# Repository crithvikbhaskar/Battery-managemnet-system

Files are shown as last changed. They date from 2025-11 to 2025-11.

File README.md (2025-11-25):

# 🔋 4-Cell Battery Management System (BMS)

This repository features a complete, production-grade **4-Cell Battery Management System (BMS)** design utilizing the **Texas Instruments BQ76920** Analog Front End (AFE) and an **STM32** microcontroller. It is designed to safely monitor, balance, and protect 4-series (4S) Lithium-Ion or Lithium Iron Phosphate (LiFePO4) battery packs.

---

## 📸 Project Visuals & Simulation

### 1. 3D Board Layout & CAD Model
The hardware layout is optimized for low-noise kelvin current sensing and thermal dissipation. It includes input RC filter stages for each cell, back-to-back low-side N-channel protection MOSFETs, and I2C pull-ups.

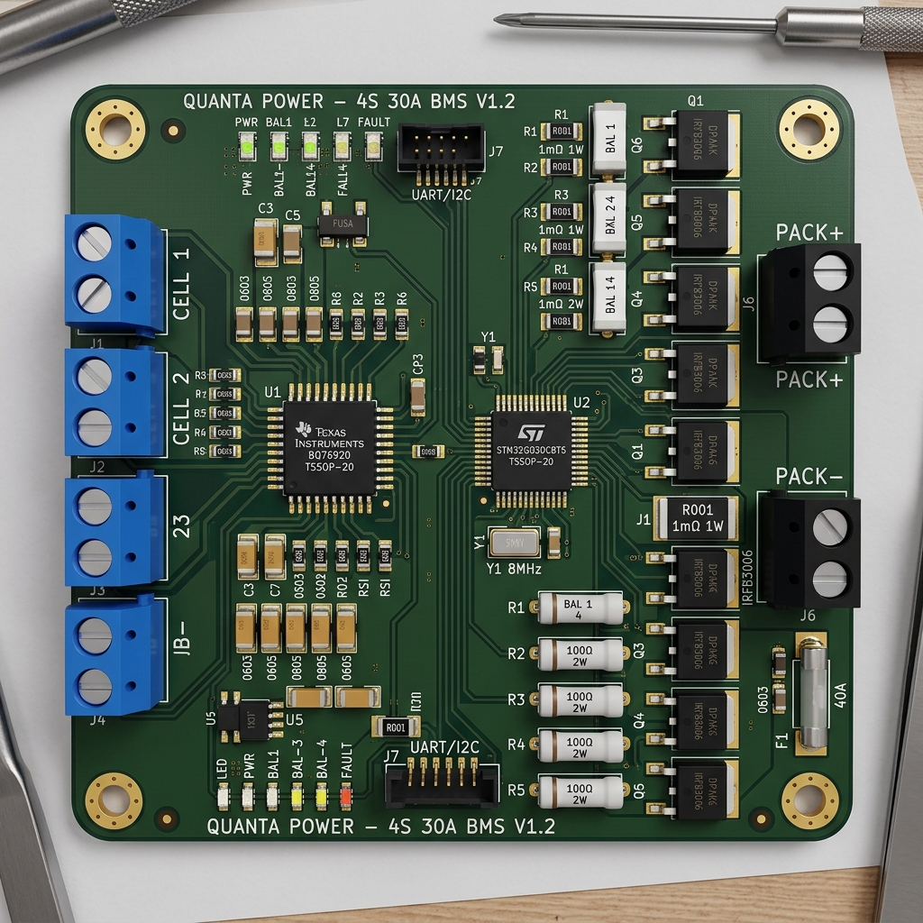
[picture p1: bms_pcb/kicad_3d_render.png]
BMS 3D PCB Render


### 2. CC/CV Charge & Passive Balancing Simulation
Below is the telemetry graph from our Python physical simulation. It models a **1.5A CC/CV charge cycle** of 4 mismatched cells. The bottom subplot shows passive cell balancing in action—shunting current away from the highest cell (Cell 3) when it exceeds 4.00V to allow the lower cells to catch up, successfully preventing overvoltage cutoffs.

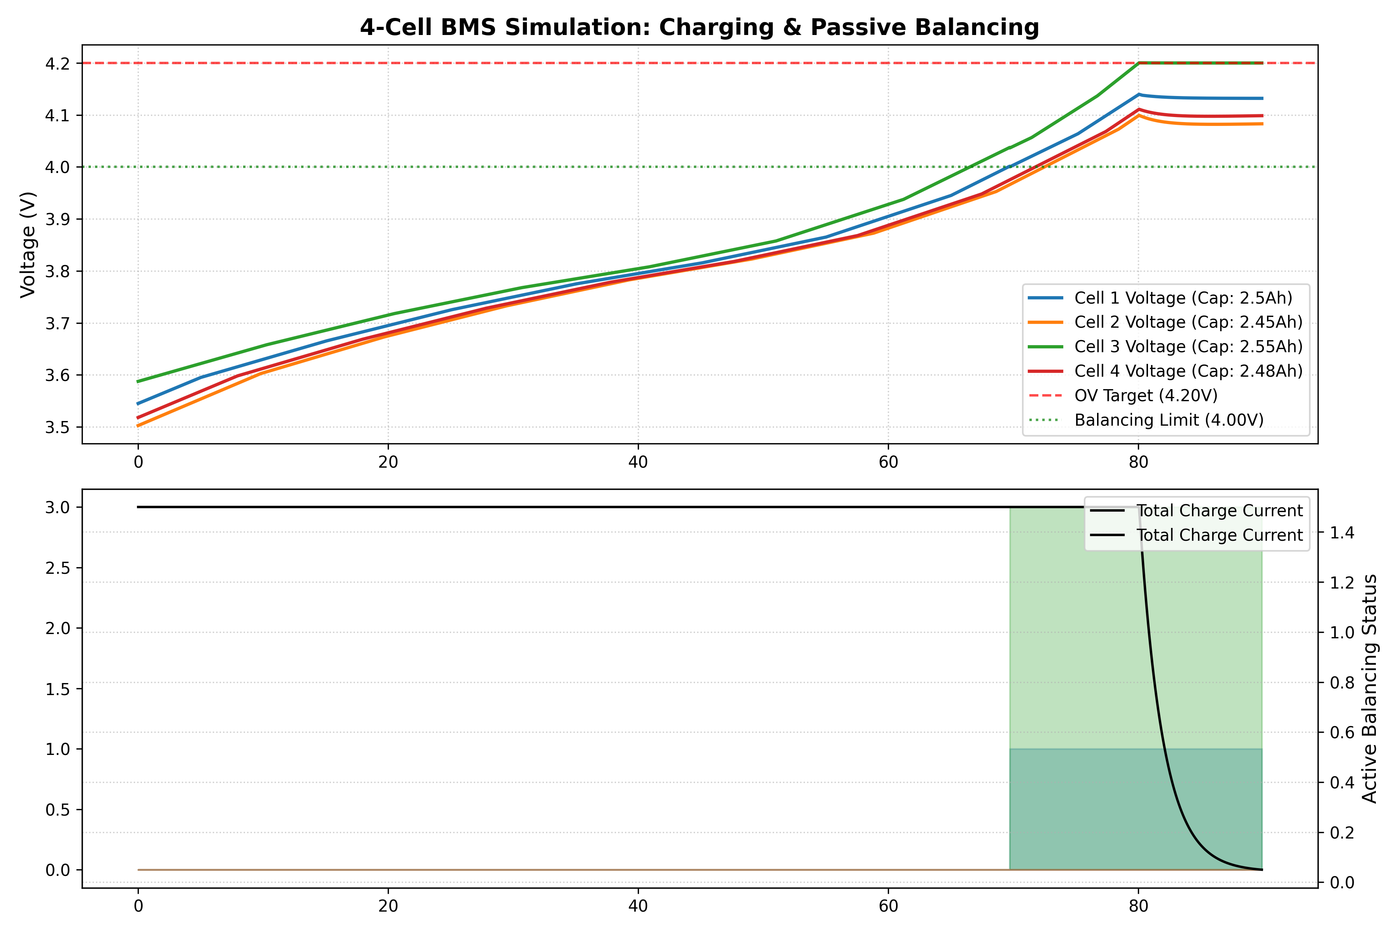
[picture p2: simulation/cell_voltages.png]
BMS Charge & Balancing Simulation Plot


---

## 🛠️ Repository Structure

*   📁 **`bms_pcb/`**: KiCad v6 CAD files containing the project metadata, schematics ([`bms_sch`](bms_pcb/bms_pcb.kicad_sch)), layout routing ([`bms_pcb`](bms_pcb/bms_pcb.kicad_pcb)), and a programmatic generator script.
*   📁 **`firmware/`**: Clean, modular C driver code for the STM32G030 microcontroller:
    *   [`bq76920.c`](firmware/Core/Src/bq76920.c) / [`.h`](firmware/Core/Inc/bq76920.h): AFE driver managing I2C transactions, CRC-8 validation, calibration, and cell bypasses.
    *   [`main.c`](firmware/Core/Src/main.c): Real-time scheduler polling telemetry every 250ms and evaluating balancing rules every 5s.
*   📁 **`simulation/`**: Python model ([`simulate_bms.py`](simulation/simulate_bms.py)) and telemetry outputs ([`cell_voltages.xlsx`](simulation/cell_voltages.xlsx), [`cell_voltages.csv`](simulation/cell_voltages.csv)).
*   📁 **`docs/`**: Electrical safety calculations ([`safety_design.md`](docs/safety_design.md)) and Mermaid flowcharts ([`flowcharts.md`](docs/flowcharts.md)).

---

## ⚡ Key Engineering & Safety Features

### 1. Robust I2C with CRC-8 (PEC)
To ensure reliable operation in noisy high-current switching environments, every single I2C read and write is protected by an 8-bit Packet Error Check (PEC) utilizing the CCITT polynomial $x^8 + x^2 + x^1 + 1$ (0x07). A single byte read checks the complete frame:
`[Write Address -> Register Address -> Read Address -> Data]`

### 2. Safety Protection Settings (Hardware Comparator Level)
Thresholds are set in hardware registers, ensuring protection FETs open instantly without waiting for MCU intervention:
*   **Cell Overvoltage (OV)**: **4.22V** ($1.0\text{s}$ delay) to prevent gas generation and plating.
*   **Cell Undervoltage (UV)**: **2.80V** ($1.0\text{s}$ delay) to protect cell health.
*   **Overcurrent in Discharge (OCD)**: **22A** ($320\text{ms}$ delay) continuous protection.
*   **Short-Circuit in Discharge (SCD)**: **89A** ($200\mu\text{s}$ delay) to prevent thermal runaway of the switches.

### 3. Waking from SHIP Mode
The BQ76920 starts in low-power SHIP mode ($<1\mu\text{A}$). The firmware implements the start-up sequence by issuing a **3ms GPIO pulse** to the TS1 pin, booting the AFE LDO to power the STM32, and then loading configurations.

---

## ⚖️ Cell Balancing Control Logic

Passive cell balancing is managed dynamically by the host MCU:
1. Telemetry scans are performed every 250ms.
2. Balancing is evaluated every 5 seconds.
3. If **any cell voltage > 4.00V** and **$\Delta V_{cell} > 20\text{mV}$**, the balancing FET for the highest cell is engaged.
4. Cell bypass is restricted to one cell at a time to prevent thermal load on the internal silicon of the AFE.

---

## ⚙️ How to Run locally

### 1. Compile the Firmware
You can compile the STM32 project using the standard GNU Arm Embedded Toolchain:
```bash
cd firmware
make
```

### 2. Run the Simulation
Execute the charging and balancing model using Python:
```bash
pip install numpy pandas matplotlib openpyxl
python simulation/simulate_bms.py
```
This updates the Excel spreadsheet (`cell_voltages.xlsx`) and regenerates the plot (`cell_voltages.png`).

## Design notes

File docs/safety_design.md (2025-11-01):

# 4-Cell BMS Safety Design Documentation

This document explains the safety-critical design decisions, electrical calculations, thermal physics, and board layout considerations for the 4-cell Battery Management System (BMS) featuring the **Texas Instruments BQ76920** analog front-end (AFE) and the **STM32G030** microcontroller.

---

## 1. Safety Threshold Calculations

The BQ76920 monitors individual cell voltages and pack current against hardware-comparator thresholds to trigger automatic shutdown of the protection FETs.

### A. Cell Overvoltage (OV) Protection
*   **Target Threshold**: $4.22\text{ V}$ ($4220\text{ mV}$)
*   **Purpose**: Prevent lithium plating, thermal runaway, and gas generation in standard Li-ion cells.
*   **AFE Configuration Math**:
    $$OV\_TRIP = \frac{V_{OV} - Offset_{mV}}{Gain_{\mu V/LSB}} \times 1000$$
    Using nominal factory calibration parameters ($Gain = 382\ \mu\text{V/LSB}$, $Offset = 0\text{ mV}$):
    $$OV\_TRIP = \frac{4220}{382/1000} \approx 11047\text{ counts}$$
    The `OV_TRIP` register (0x09) stores the upper 8 bits of the 14-bit ADC trip point (shifted right by 6 bits):
    $$OV\_TRIP\_REG = \frac{11047}{64} \approx 172 \text{ (0xAC)}$$
*   **Hardware Delay**: Configured via `PROTECT3` register to $1.0\text{ second}$ to ignore transient spikes during regenerative braking or high current pulses.

### B. Cell Undervoltage (UV) Protection
*   **Target Threshold**: $2.80\text{ V}$ ($2800\text{ mV}$)
*   **Purpose**: Prevent copper shunt formation and irreversible capacity loss due to over-discharge.
*   **AFE Configuration Math**:
    $$UV\_TRIP = \frac{2800}{0.382} \approx 7330\text{ counts}$$
    $$UV\_TRIP\_REG = \frac{7330}{64} \approx 114 \text{ (0x72)}$$
*   **Hardware Delay**: Configured to $1.0\text{ second}$ to prevent false UV trips during high-inrush loads.

### C. Overcurrent in Discharge (OCD) Protection
*   **Target Threshold**: $22.0\text{ A}$ continuous
*   **Sense Resistor ($R_{sns}$)**: $1.0\ \text{m}\Omega$ ($1000\ \mu\Omega$)
*   **Threshold Voltage ($V_{OCD}$)**:
    $$V_{OCD} = I_{OCD} \times R_{sns} = 22\text{ A} \times 1\text{ m}\Omega = 22\text{ mV}$$
*   **AFE Register Configuration**:
    Looking at the BQ76920 datasheet's `PROTECT2` table:
    *   $V_{OCD} = 22\text{ mV}$ maps directly to threshold code `0x0B` ($22\text{ mV}$ nominal with $RSNS = 1$).
*   **OCD Delay**: Configured to $320\text{ ms}$ to allow for transient inrush currents without opening protection switches.

### D. Short-Circuit in Discharge (SCD) Protection
*   **Target Threshold**: $89.0\text{ A}$ instant peak
*   **Threshold Voltage ($V_{SCD}$)**:
    $$V_{SCD} = I_{SCD} \times R_{sns} = 89\text{ A} \times 1\text{ m}\Omega = 89\text{ mV}$$
*   **AFE Register Configuration**:
    Looking at the `PROTECT1` register table:
    *   $V_{SCD} = 89\text{ mV}$ maps to threshold code `0x03` ($89\text{ mV}$ nominal with $RSNS = 1$).
*   **SCD Delay**: Configured to $200\ \mu\text{s}$ (code `0x00`) to protect the MOSFETs from thermal failure under dead-short conditions.

---

## 2. Cell Balancing Physics & Calculations

The BMS implements **passive cell balancing**, where excess energy from higher-voltage cells is dissipated as heat.

```
       Cell (+) ────┬──────────────────────────┐
                    │                          │
                   [R_f] (100 Ohm)             │
                    │                    [External Bypass Path]
                    ├───────┐ (Gate)           │
                    │     [ Q_bal ] (PMOS)     │
                    │       │                  │
                [C_filter]  ├───[R_bal] (39R) ──┤
                    │       │                  │
       Cell (-) ────┴───────┴──────────────────┘
```

### A. Balancing Current Calculation (Internal Balancing)
In internal balancing mode, the BQ76920 turns on an internal bypass FET with $R_{DS(on)} \approx 25\ \Omega$ between $VC_n$ and $VC_{n-1}$. The current is drawn through the input filter resistors ($R_f = 100\ \Omega$):
$$I_{bal} = \frac{V_{cell}}{R_f(VC_n) + R_{DS(on)} + R_f(VC_{n-1})} = \frac{4.2\text{ V}}{100\ \Omega + 25\ \Omega + 100\ \Omega} = \frac{4.2\text{ V}}{225\ \Omega} \approx 18.7\text{ mA}$$

*   **Internal Power Dissipation**:
    $$P_{int} = I_{bal}^2 \times R_{DS(on)} = (0.0187\text{ A})^2 \times 25\ \Omega \approx 8.7\text{ mW per channel}$$
    If balancing 2 cells simultaneously: $P_{total\_int} \approx 17.4\text{ mW}$. This is negligible and represents zero thermal risk to the AFE chip.

### B. Balancing Current Calculation (External Balancing)
For larger battery packs (e.g., $>10\text{ Ah}$), $18.7\text{ mA}$ is too small. We can add an external PMOS and a power balancing resistor ($R_{bal} = 39\ \Omega$):
$$I_{bal\_ext} = \frac{V_{cell}}{R_{bal}} = \frac{4.2\text{ V}}{39\ \Omega} \approx 108\text{ mA}$$

*   **External Power Dissipation**:
    $$P_{ext} = I_{bal\_ext}^2 \times R_{bal} = (0.108\text{ A})^2 \times 39\ \Omega \approx 0.45\text{ W}$$
    The balancing resistor must be a $1\text{ W}$ rated SMT resistor (e.g. 2512 package) to safely handle this heat.

---

## 3. Low-Side Switching Implications

The BMS uses a low-side switching topology, meaning the N-channel protection FETs are placed in the negative return path between $BAT-$ and $PACK-$.

```
   BAT+ ────────────────────────────────────────────────────────── PACK+
   
   BAT- ───[ Sense Resistor ]───[ DSG FET ]───[ CHG FET ]───────── PACK-
               (VSS ground)                                  (System Ground)
```

### A. Ground Reference Separation
*   **FETs Closed (Normal)**: $PACK-$ is connected to $BAT-$. The system ground reference ($PACK-$) and chip reference ($VSS$) are at nearly the same potential (separated only by the millivolt drop of $R_{sns}$ and the FET $R_{DS(on)}$).
*   **FETs Open (Fault State)**: When the FETs turn off due to a fault, the connection between $BAT-$ and $PACK-$ is severed. If a charger is attached, $PACK-$ can float to the full charger voltage (e.g., $+16.8\text{ V}$) relative to $BAT-$.

### B. External Communication Hazard
If the host microcontroller or an external debugger (like an ST-Link) is referenced to $PACK-$ (system ground) and communicates with the BMS (referenced to $VSS$ ground) via non-isolated I2C:
*   Opening the FETs creates a ground loop, driving the AFE I2C pins ($SCL/SDA$) negative relative to the floating $PACK-$.
*   This will exceed the absolute maximum ratings of the microcontroller pins, leading to hardware destruction.
*   **Solution**: All external communication links crossing the low-side isolation boundary must use digital isolators (e.g., ADuM1250 for I2C) to isolate ground references completely.

---

## 4. Hardware Safeguards and PCB Layout Rules

To ensure safety and measurement accuracy, the physical board layout must follow these guidelines:

1.  **Kelvin Connections**: The trace routes from the sense resistor ($R_{sns}$) to the $SRP$ and $SRN$ pins must be routed as a differential pair directly from the sense pads, keeping them away from high-current switching paths.
2.  **AFE Filter Capacitor Placement**: The RC filter components for the cell inputs ($VC0$ to $VC4$) must be placed as close to the BQ76920 pins as possible to filter high-frequency switching noise before it reaches the internal ADC.
3.  **High Current Thermal Sinks**: The copper planes connecting the protection FETs must be wide and thick (2oz copper recommended) with thermal vias to dissipate heat from high charge/discharge current loads.

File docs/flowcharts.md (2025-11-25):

# 4-Cell BMS Operational Flowcharts

This document provides visual flowcharts of the core firmware logic, represented in Mermaid syntax.

---

## 1. System Boot and AFE Initialization Sequence

This flowchart shows how the STM32 controller wakes up the BQ76920 AFE, reads the factory calibration coefficients, and enables the system protection circuits.

```mermaid
graph TD
    A([Power On / Reset]) --> B[GPIO and System Clock Config]
    B --> C[AFE_BOOT Pin PB1 Set HIGH]
    C --> D[Delay 3 ms for TS1 boot pulse]
    D --> E[AFE_BOOT Pin PB1 Set LOW]
    E --> F[Delay 10 ms for REGOUT stabilization]
    F --> G[Initialize I2C1 Peripheral]
    G --> H[Read BQ76920 Calibration: ADCGAIN & ADCOFFSET]
    H --> I[Configure SYS_CTRL1: Enable ADC, Set Ext Thermistor]
    I --> J[Configure SYS_CTRL2: Enable Coulomb Counter]
    J --> K[Configure Protection Limits: SCD, OCD, OV, UV]
    K --> L[Clear Status Register: Write 0xFF to SYS_STAT]
    L --> M[Enable Protection FETs: CHG_ON = 1, DSG_ON = 1]
    M --> N([BMS Main Loop Active])
    
    style C fill:#f9f,stroke:#333,stroke-width:2px
    style H fill:#bbf,stroke:#333,stroke-width:2px
    style M fill:#bfb,stroke:#333,stroke-width:2px
```

---

## 2. ALERT Interrupt and Fault Handling Routine

The BQ76920 drives the ALERT pin high when it detects a hardware fault. This triggers an EXTI interrupt on the STM32 to protect the battery pack immediately.

```mermaid
graph TD
    A([AFE ALERT Pin PB0 transitions LOW -> HIGH]) --> B[EXTI Rising Edge Interrupt ISR]
    B --> C[Read SYS_STAT Register via I2C]
    C --> D{Read Successful?}
    D -- No --> E[Emergency Shutdown: Force CHG_ON=0, DSG_ON=0]
    D -- Yes --> F{Any Fault Bits Active?}
    F -- No --> G[Exit Interrupt]
    F -- Yes --> H[Update global hBms.fault_status]
    H --> I{Decode Fault Type}
    
    I -->|SCD / OCD / DEVICE_XREADY| J[Critical Pack Fault: Disable CHG and DSG FETs]
    I -->|Cell Overvoltage - OV| K[Overcharge Fault: Disable CHG FET]
    I -->|Cell Undervoltage - UV| L[Overdischarge Fault: Disable DSG FET]
    
    J --> M[Enter Safe Lock-out State]
    K --> N[Wait for OV condition to clear]
    L --> O[Wait for UV condition to clear]
    
    N --> P[Write 1 to clear OV bit in SYS_STAT]
    O --> Q[Write 1 to clear UV bit in SYS_STAT]
    P --> R{OV cleared successfully?}
    Q --> S{UV cleared successfully?}
    
    R -- Yes --> T[Re-enable CHG FET]
    S -- Yes --> U[Re-enable DSG FET]
    
    style E fill:#f99,stroke:#333,stroke-width:2px
    style J fill:#f99,stroke:#333,stroke-width:2px
    style T fill:#bfb,stroke:#333,stroke-width:2px
    style U fill:#bfb,stroke:#333,stroke-width:2px
```

---

## 3. Passive Cell Balancing State Machine

This algorithm runs in the main loop every 5 seconds. It determines if cell balancing is required and selects the target cell to bypass charge current.

```mermaid
graph TD
    A([Balancing Task Triggered]) --> B{Any active faults present?}
    B -- Yes --> C[Disable Balancing: Write 0 to CELLBAL1]
    B -- No --> D{Is Charging Active?}
    D -- No --> C
    D -- Yes --> E[Read Cell Voltages: cell_voltages_mv 0..3]
    E --> F[Find max_voltage, min_voltage, and max_index]
    F --> G[Calculate delta_V = max_voltage - min_voltage]
    G --> H{max_voltage > 4.00V AND delta_V > 20mV?}
    H -- No --> C
    H -- Yes --> I[Enable Balance Bypass for Cell max_index]
    I --> J[Write 1 << max_index to CELLBAL1 Register]
    J --> K[Update hBms.balancing_mask]
    K --> L([Return to Main Loop])
    C --> L
    
    style C fill:#fbb,stroke:#333,stroke-width:2px
    style J fill:#bfb,stroke:#333,stroke-width:2px
```

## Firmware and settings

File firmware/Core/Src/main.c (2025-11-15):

/**
 ******************************************************************************
 * @file           : main.c
 * @brief          : Main program body for BMS Controller
 ******************************************************************************
 */

#include "main.h"
#include "bq76920.h"

/* Peripheral Handles */
I2C_HandleTypeDef hi2c1;

/* Local variables */
uint32_t last_measurement_tick = 0;
uint32_t last_balancing_tick = 0;

/* Private Function Prototypes */
static void MX_GPIO_Init(void);
static void MX_I2C1_Init(void);
static void AFE_Boot(void);
static void Run_CellBalancing_Algorithm(void);

/**
 * @brief  The application entry point.
 * @retval int
 */
int main(void)
{
    /* Initialize GPIOs and I2C */
    MX_GPIO_Init();
    
    /* Boot the BQ76920 AFE via TS1 boot pulse */
    AFE_Boot();
    
    /* Initialize I2C peripheral */
    MX_I2C1_Init();

    /* Initialize BQ76920 AFE and configuration registers */
    if (BQ76920_Init(&hi2c1) != HAL_OK) {
        Error_Handler();
    }

    last_measurement_tick = HAL_GetTick();
    last_balancing_tick = HAL_GetTick();

    /* Infinite loop */
    while (1)
    {
        uint32_t current_tick = HAL_GetTick();

        /* Task 1: Read cell voltages, current, and temperature every 250ms */
        if (current_tick - last_measurement_tick >= 250) {
            last_measurement_tick = current_tick;

            /* Check if any faults are present in AFE */
            if (BQ76920_IsFaultActive()) {
                /* System is in fault! Alert handler was called by EXTI,
                   but we double-check here to ensure safety. */
                BQ76920_SetFETs(false, false);
            } else {
                /* Read telemetry */
                BQ76920_ReadVoltages();
                BQ76920_ReadCurrent();
                BQ76920_ReadTemperature();
            }
        }

        /* Task 2: Evaluate and execute cell balancing every 5 seconds */
        if (current_tick - last_balancing_tick >= 5000) {
            last_balancing_tick = current_tick;
            
            /* Run cell balancing only if FETs are active and no faults are present */
            if (!BQ76920_IsFaultActive() && hBms.chg_fet_state) {
                Run_CellBalancing_Algorithm();
            } else {
                /* Disable balancing during fault or discharge/idle with open FETs */
                BQ76920_SetBalancing(0);
            }
        }

        /* Standard STM32 low-power sleep while waiting for timer interrupt */
        HAL_Delay(10);
    }
}

/**
 * @brief Wakes up BQ76920 from SHIP mode by sending a >1ms pulse to TS1
 */
static void AFE_Boot(void) {
    /* Set Boot control pin high to inject current into TS1 pin */
    HAL_GPIO_WritePin(AFE_BOOT_PORT, AFE_BOOT_PIN, GPIO_PIN_SET);
    HAL_Delay(3); /* Hold for 3ms (AFE needs >1ms pulse) */
    HAL_GPIO_WritePin(AFE_BOOT_PORT, AFE_BOOT_PIN, GPIO_PIN_RESET);
    HAL_Delay(10); /* Wait for internal LDO (REGOUT) to stabilize */
}

/**
 * @brief Standard cell balancing algorithm (passive bypass)
 * Balances the highest voltage cell if it is above 4.0V and delta V > 20mV
 */
static void Run_CellBalancing_Algorithm(void) {
    uint16_t max_v = hBms.cell_voltages_mv[0];
    uint16_t min_v = hBms.cell_voltages_mv[0];
    uint8_t max_idx = 0;

    /* Find minimum, maximum, and index of the highest cell */
    for (int i = 1; i < 4; i++) {
        if (hBms.cell_voltages_mv[i] > max_v) {
            max_v = hBms.cell_voltages_mv[i];
            max_idx = i;
        }
        if (hBms.cell_voltages_mv[i] < min_v) {
            min_v = hBms.cell_voltages_mv[i];
        }
    }

    uint16_t delta_v = max_v - min_v;

    /* Passive balancing criteria:
       1. Max cell is above 4000mV (balancing threshold)
       2. Imbalance delta V exceeds 20mV
       3. We only balance one cell at a time to prevent thermal load on AFE */
    if (max_v > 4000 && delta_v > 20) {
        /* Enable balance switch for the highest cell (bit mask 1 << index) */
        BQ76920_SetBalancing(1 << max_idx);
    } else {
        /* Turn off all cell balancing */
        BQ76920_SetBalancing(0);
    }
}

/**
 * @brief GPIO Initialization Function
 */
static void MX_GPIO_Init(void) {
    /* Pins are configured on STM32G0:
       - PB1 (AFE_BOOT_PIN) as Output (Push-Pull, Pull-down)
       - PB0 (AFE_ALERT_PIN) as Input (EXTI interrupt on rising edge, Pull-down)
    */
    HAL_GPIO_WritePin(AFE_BOOT_PORT, AFE_BOOT_PIN, GPIO_PIN_RESET);
}

/**
 * @brief I2C1 Initialization Function
 */
static void MX_I2C1_Init(void) {
    /* Initialize I2C1 peripheral at 100kHz standard mode */
    hi2c1.Instance = 1;
}

/**
 * @brief EXTI line detection callback (ALERT pin interrupt)
 */
void HAL_GPIO_EXTI_Rising_Callback(uint16_t GPIO_Pin) {
    if (GPIO_Pin == AFE_ALERT_PIN) {
        /* Execute safety interrupt routine */
        BQ76920_HandleAlert();
    }
}

/**
 * @brief Error handler function
 */
void Error_Handler(void) {
    /* Disable protection FETs immediately on error */
    BQ76920_SetFETs(false, false);
    while (1) {
        /* Blink an LED or enter lock-out state */
    }
}

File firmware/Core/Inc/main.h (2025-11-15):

/**
 ******************************************************************************
 * @file           : main.h
 * @brief          : Header for main.c file.
 *                   This file contains the common defines of the application.
 ******************************************************************************
 */

#ifndef MAIN_H
#define MAIN_H

#ifdef __cplusplus
extern "C" {
#endif

/* Include standard HAL (we will provide a mock header so it compiles standalone) */
#include "stm32g0xx_hal.h"

/* Exported functions prototypes */
void Error_Handler(void);

/* Pin Mappings for the BMS Circuit */
#define AFE_ALERT_PIN           GPIO_PIN_0
#define AFE_ALERT_PORT          GPIOB
#define AFE_BOOT_PIN            GPIO_PIN_1
#define AFE_BOOT_PORT           GPIOB

#define I2C_SCL_PIN             GPIO_PIN_11
#define I2C_SCL_PORT            GPIOA
#define I2C_SDA_PIN             GPIO_PIN_12
#define I2C_SDA_PORT            GPIOA

#ifdef __cplusplus
}
#endif

#endif /* MAIN_H */

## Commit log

2025-11-05 hardware: design 4-cell BMS schematic and PCB layout in KiCad
    [bms_pcb.kicad_pcb, bms_pcb.kicad_sch]
2025-11-10 firmware: implement BQ76920 I2C driver with CRC-8 and calibration
2025-11-20 simulation: add cell balancing charge cycle simulation and telemetry
    [cell_voltages.csv, cell_voltages.xlsx]
2025-11-25 docs: add operational flowcharts and 3D board render
